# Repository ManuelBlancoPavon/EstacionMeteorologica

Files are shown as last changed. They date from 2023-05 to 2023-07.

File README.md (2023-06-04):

# Para sanarlo hay que estudiarlo (Estación meteorológica)

## Presentación

Esta estación meteorológica sirve para medir la temperatura, humedad, presión, luxes, índice UV, velocidad del viento, dirección del viento y precipitaciones.
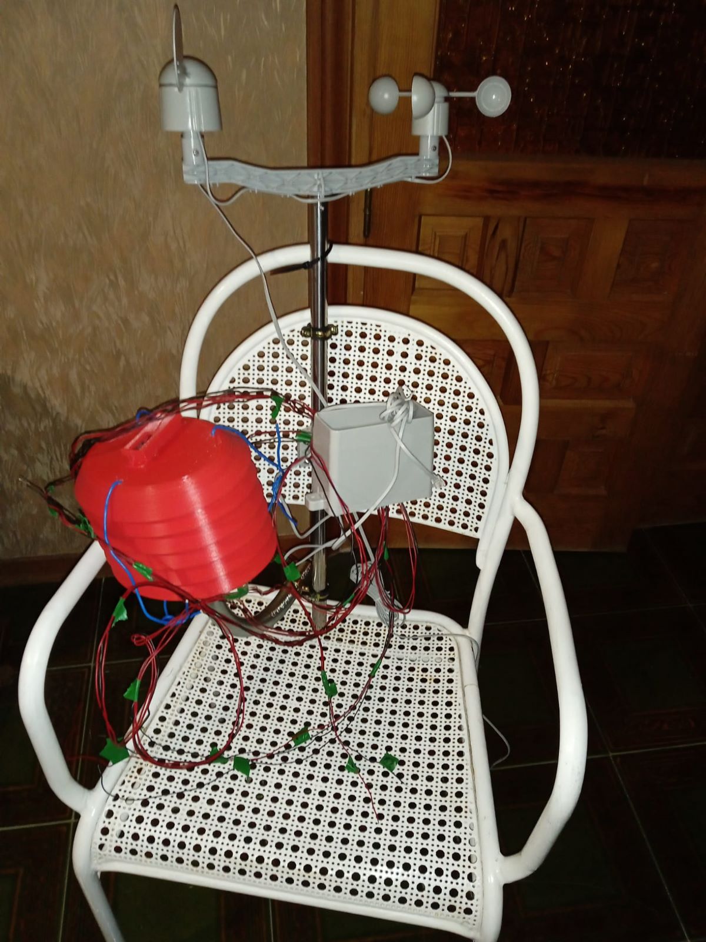
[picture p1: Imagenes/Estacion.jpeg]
Estación


## Pagina Web donde ver los datos del tiempo
>
> En construcción.
>
## Materiales

- 1x Raspberry Pi Pico W
- 1x BME280
- 1x LTR390
- 1x MQ-135
- 1x [Kit de anemómetro, veleta y pluviómetro.](https://www.argentdata.com/catalog/product_info.php?products_id=145)
- 2x Cables STEMMA QT
- 2x Conectores RJ11
- 9x Conectores de tornillo de 2 pines
- 1x Resistencias de 2k ohm
- 2x Resistencia de 4.7k ohm
- 1x Perforad

## Esquema de conexiones

- Los cables de color ocre son conexiones hechas con estaño hechas por debajo.
- Es mejor soldar a la placa unos pines hembra para poder sacar y poner la Raspberry Pi Pico W.
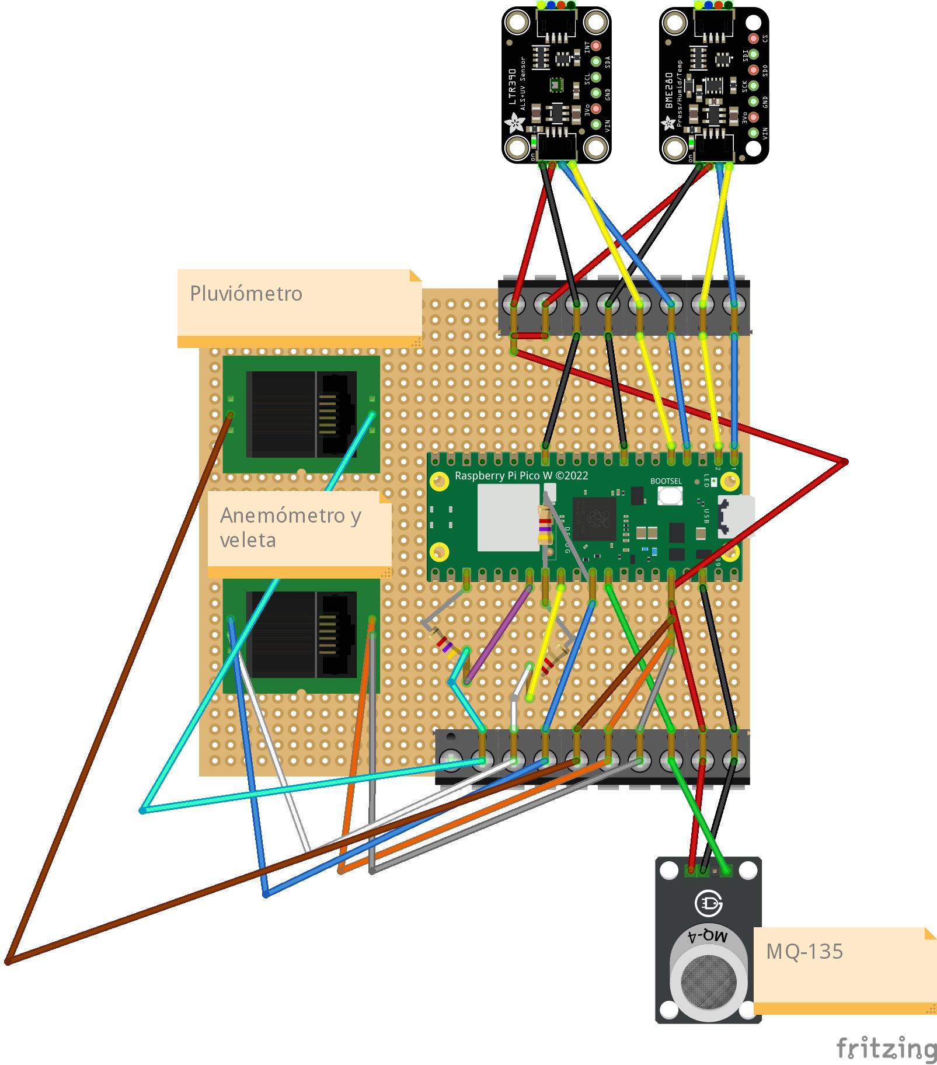
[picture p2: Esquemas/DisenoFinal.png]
Esquema

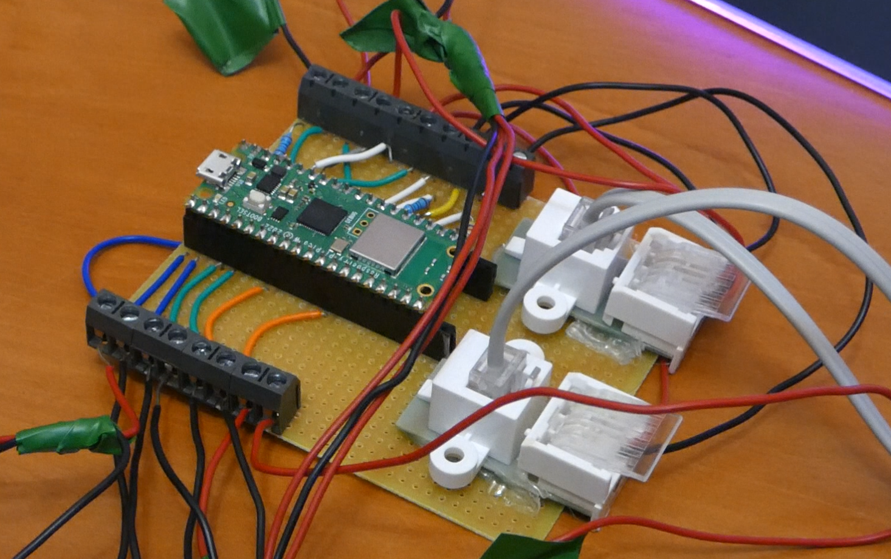
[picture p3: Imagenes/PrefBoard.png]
PrefBoard


## Programación

### Raspberry Pi Pico W

1. Mantén el botón BOOT presionado y conecta la Raspberry Pi Pico W al ordenador.
2. Descargar CircuitPython 8.x [aquí](https://circuitpython.org/board/raspberry_pi_pico_w/).
3. Arrastrar el archivo .u2f a la carpeta de la Raspberry Pi Pico W.
4. Descargar el bundle versión 8.x [aquí](https://circuitpython.org/libraries).
5. Descomprime el bundle y copia a la carpeta lib de las Raspberry Pi Pico W las siguientes librerías:

- adafruit_bme280
- adafruit_httpserver
- adafruit_register
- asyncio
- adafruit_ltr390.mpy
- adafruit_ticks.mpy
- adafruit_datetime.mpy
- adafruit_requests.mpy

6.Descargue Thonny [aquí](https://thonny.org/).
7.Abra Thonny y seleccione la Raspberry Pi Pico W como dispositivo.
8.Copie la carpeta de tests a la Raspberry Pi Pico W.
9.Compruebe que cada sensor funcione.
10.Copie el archivo main.py y settings.json a la Raspberry Pi Pico W.
11.Modifique el settings.json con los datos de su red wifi
12.Ejecute el archivo main.py
13.Y en su navegador vaya a la dirección ip 192.168.1.160/data (o la que tenga asignada) y vera como cada 15 segundos o los que quiera se actualizan los datos.
14.Cabe destacar que solo empezara a dar datos cuando los minutos acaben en 0 o 5 para que los datos cuando sean almacenados queden más bonitas las fechas.

### Servidor

#### Poniendo en marcha la base de datos

1. Descargue e instale MariaDB [aquí](https://mariadb.org/download/).
2. Ejecute script.sql en la base de datos.

#### Almacenando datos en la base de datos

1. Instale los siguientes módulos de python con pip install -r requirements.txt.
2. Descargue el archivo store.py y ejecútelo configurando cada cuánto tiempo quiere almacenar los datos.
3. Lo tendrá que hacer que se ejecute en segundo plano.
4. Ten en cuenta que este programa se adapta automáticamente a la cantidad de tiempo que hayas puesta en la configuración de la Raspberry PI Pico W.

#### Página Web

1. Descargue la carpeta app y ejecute main.py.
2. Recuerde que en host tiene que poner la ip de su ordenador.
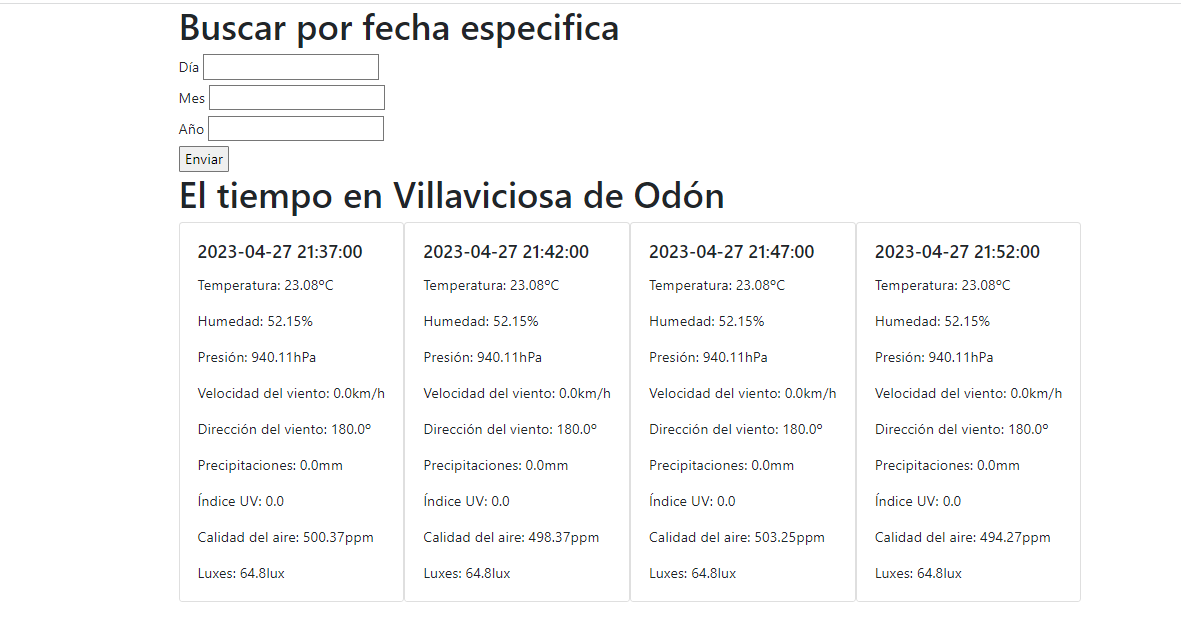
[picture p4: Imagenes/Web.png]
Web


### Creación de los procesos en segundo plano

Esto solo se aplica para Linux (yo lo he hecho en Ubuntu 22.04 aunque debería funcionar para cualquier Linux).

1. Descargue los archivos archivos tiempo_store.service y tiempo_web.service y ponga los en /etc/systemd/system.
2. Cambie en los dos archivos las rutas de donde esta la carpeta y donde esta el archivo que se tiene que ejecutar en los campos WorkingDirectory y ExecStart, no se olvide de poner su nombre de usuario en el campo User.
3. Ejecute sudo systemctl daemon-reload.
4. Ejecute sudo systemctl start tiempo_store.service y sudo systemctl start tiempo_web.service para iniciarlos.
5. Ejecute sudo systemctl enable tiempo_store.service y sudo systemctl enable tiempo_web.service para que se inicien al encender el ordenador.
6. Ejecute sudo systemctl status tiempo_store.service y sudo systemctl status tiempo_web.service para comprobar que se están ejecutando.
7. Una cosa buena de este sistema es que si uno de los procesos da error se reiniciara automáticamente.

## Montaje

1. Imprime una Stevenson screen para que los sensores no estén expuestos al sol y solo midan la temperatura del aire aunque os recomiendo que el sensor grid lo imprimáis un poco más pequeño para que quepa. Luego hacer un agujero en la parte de abajo para llevar los cables [Descargar](https://www.thingiverse.com/thing:1718334/files). Podéis poner los sensores en el sensor grid y os quedaría tal que así:
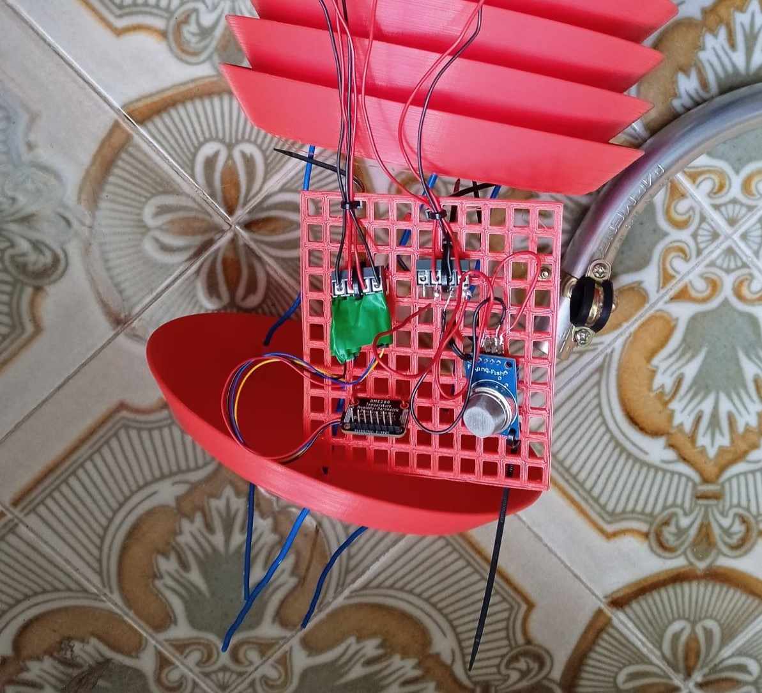
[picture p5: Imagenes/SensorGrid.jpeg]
SensorGrid

Y para el LTR390 tenéis esta carcasa [Descargar](https://www.thingiverse.com/thing:5388692). Aunque yo he hecho una modificación para que sea un poco más amplia y entre mejor lo tenéis en la carpeta impresora 3D. Y luego lo podéis poner en la parte de arriba de la Stevenson screen con silicona caliente y hacer un agujero en la parte de abajo para llevar los cables.

## Agradecimientos

Muchas gracias a mi familia, mis amigos y profesores por el apoyo que me han dado para hacer este proyecto.

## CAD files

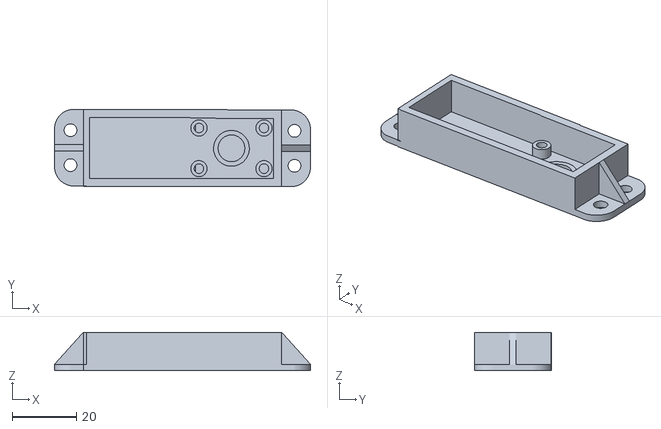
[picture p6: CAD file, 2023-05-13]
Impresora3D/LTR390_case.stl
80.0 x 24.0 x 12.0

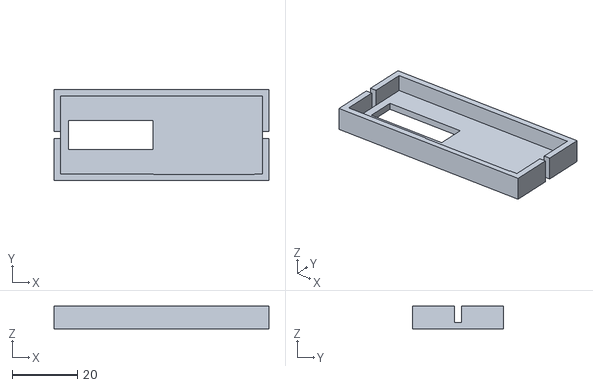
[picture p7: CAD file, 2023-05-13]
Impresora3D/LTR390_tape.stl
66.0 x 27.8 x 7.00

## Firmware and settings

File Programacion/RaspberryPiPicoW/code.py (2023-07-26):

import asyncio
import board
import keypad
import time
import math
import analogio
import busio
import os
import adafruit_ltr390
from adafruit_bme280 import basic as adafruit_bme280
from adafruit_httpserver.server import HTTPServer
from adafruit_httpserver.request import HTTPRequest
from adafruit_httpserver.response import HTTPResponse
from adafruit_httpserver.methods import HTTPMethod
from adafruit_httpserver.mime_type import MIMEType
import ipaddress
import wifi
import adafruit_datetime
import json
import socketpool
import adafruit_requests
import microcontroller

## Variables
# Wifi
ipv4 =  ipaddress.IPv4Address("192.168.1.160")
netmask =  ipaddress.IPv4Address("255.255.255.0")
gateway =  ipaddress.IPv4Address("192.168.1.1")
wifi.radio.set_ipv4_address(ipv4=ipv4,netmask=netmask,gateway=gateway)

ssid = os.getenv("WIFI_SSID")
password = os.getenv("WIFI_PASSWORD")

while True:
    try:
        print("Connecting to", ssid)
        wifi.radio.connect(ssid, password)
        print("Connected to", ssid)
        ipv4 = ipaddress.ip_address("8.8.8.8")
        print("Ping google.com: %f ms" % (wifi.radio.ping(ipv4)*1000))
        break
    except Exception as e:
        print("Error:\n", str(e))
        time.sleep(40)

pool = socketpool.SocketPool(wifi.radio)
server = HTTPServer(pool, "/static")

url = "http://worldtimeapi.org/api/timezone/Europe/Madrid"
requests = adafruit_requests.Session(pool)
# Pluviometro
agua = 0
# Anemometro
vueltas = 0
radio = 9.0
intervalo = 900
ajuste = 1.18
limite = 1000
# Veleta
volts = {0.4: 0,
         2.8: 90,
         1.8: 180,
         0.1: 270,
         1.2: 45,
         2.3: 135,
         0.8: 225,
         0.2: 315,
         1.4: 22.5,
         2.9: 112.5,
         2.6: 157.5,
         2.0: 202.5,
         0.7: 247.5,
         0.3: 292.5,
         0.6: 337.5}

## Sensores
# MQ-135
MQ135 = analogio.AnalogIn(board.GP27)
# BME280
i2c = busio.I2C(board.GP1, board.GP0)  # SCL, SDA
bme280 = adafruit_bme280.Adafruit_BME280_I2C(i2c)
# LTR390
i2c = busio.I2C(board.GP3, board.GP2)  # SCL, SDA
ltr390 = adafruit_ltr390.LTR390(i2c)
# Veleta
analog_value = analogio.AnalogIn(board.GP26)

### Codigo
## Wifi
# Conectarse a la red

print(f"Listening on http://{wifi.radio.ipv4_address}:80")
server.start(str(wifi.radio.ipv4_address))
def calcularMM():
    global agua
    mm = agua * 0.2794
    return mm

def calcularVelocidad(tiempo):
    global vueltas
    circunferencia = (2 * math.pi) * radio
    rotaciones = vueltas / 2.0
    
    distKM = (circunferencia * rotaciones) / 100000
    
    kms = distKM / tiempo
    kmh = kms * 3600
    
    return kmh * ajuste

def calcularppm():
    calibracion = 0.00322265625
    valorBruto = MQ135.value
    voltaje = valorBruto * 3.3 / 65536
    ppm = voltaje / calibracion
    return ppm

async def catch_pin_transitions2(pin):
    """Print a message when pin goes low and when it goes high."""
    with keypad.Keys((pin,), value_when_pressed=False) as keys:
        while True:
            event = keys.events.get()
            if event:
                if event.released:
                    global agua
                    agua += 1
            await asyncio.sleep(0)

async def catch_pin_transitions(pin):
    """Print a message when pin goes low and when it goes high."""
    with keypad.Keys((pin,), value_when_pressed=False) as keys:
        while True:
            event = keys.events.get()
            if event:
                if event.released:
                    global vueltas
                    vueltas += 1
            await asyncio.sleep(0)
velocidad = 0
ppm = 0
direccion = 0
temperatura = 0
humedad = 0
presion = 0
precipitaciones = 0
uvi = 0
lux = 0

async def principal():
    while True:
        try:
            global vueltas
            global agua
            global intervalo
            global velocidad
            global ppm
            global direccion
            global temperatura
            global humedad
            global presion
            global precipitaciones
            global uvi
            global lux
            agua = 0
            vueltas = 0
            await asyncio.sleep(intervalo)
            ppm = calcularppm()
            temperatura = bme280.temperature
            humedad = bme280.relative_humidity
            presion = bme280.pressure
            precipitaciones = calcularMM()
            uvi = ltr390.uvi
            lux = ltr390.lux
            velocidad = calcularVelocidad(intervalo)
            voltios = round((analog_value.value * 3.33333) / 65535, 1)
            print("Velocidad del viento", velocidad, "km/h")
            print("Temperatura: %0.1f C" % bme280.temperature)
            print("Humedad: %0.1f %%" % bme280.relative_humidity)
            print("Presion: %0.1f hPa" % bme280.pressure)
            print("Precipitaciones: ", calcularMM(), "mm")
            print("Indice de radiacion UV:", ltr390.uvi)
            print("Luxes: ", ltr390.lux, "iluminancia")
            print("Concentracion de gases: %.2f ppm" % ppm)
            if not voltios in volts:
                direccion = -1
                print("Direccion del viento desconocida")
            else:
                direccion = str(volts[voltios])
                print("Direccion del viento: " + str(volts[voltios]))
                
        except Exception as e:
            print("Error en principal")
            time.sleep(5)
            microcontroller.reset()

async def updateServer():
    timer = 0
    while True:
        try:
            print(timer)
            await asyncio.sleep(0.5)
            timer += 0.5
            server.poll()
        except Exception as e:
            print("Error en enviando los datos")
            time.sleep(5)
            microcontroller.reset()
        
@server.route("/data") 
def cpu_information_handler(request: HTTPRequest):
    try:
        global velocidad
        global ppm
        global direccion
        global temperatura
        global humedad
        global presion
        global precipitaciones
        global uvi
        global lux
        data = {
            "velocidad": round(velocidad, 2),
            "temperatura": round(temperatura, 2),
            "humedad": round(humedad, 2),
            "presion": round(presion, 2),
            "precipitaciones": round(precipitaciones, 2),
            "uvi": round(uvi, 2),
            "luxes": round(lux, 2),
            "direccion": direccion,
            "ppm": round(ppm, 2)
        }

        with HTTPResponse(request, content_type=MIMEType.TYPE_JSON) as response:
            response.send(json.dumps(data))
            
    except Exception as e:
        print("Error actualizando los datos")
        time.sleep(5)
        microcontroller.reset()

async def main():
    interrupt_task = asyncio.create_task(catch_pin_transitions(board.GP22))
    interrupt_task2 = asyncio.create_task(catch_pin_transitions2(board.GP21))
    server_task = updateServer()
    print_task = asyncio.create_task(principal())
    check_internet = asyncio.create_task(comprobarInternet())
    await asyncio.gather(interrupt_task, interrupt_task2, print_task, server_task, check_internet)

async def comprobarInternet():
    while True:
        try:
            await asyncio.sleep(300)
            ipv4 = ipaddress.ip_address("8.8.8.8")
            print("Ping google.com: %f ms" % (wifi.radio.ping(ipv4)*1000))
        except Exception as e:
            print("Se ha ido la conexion a internet")
            time.sleep(5)
            microcontroller.reset()

while True:
    response = requests.get(url)
    jsonTiempo = response.json()
    strTiempo = jsonTiempo['datetime']
    objTiempo = adafruit_datetime.datetime.fromisoformat(strTiempo)
    minutos = objTiempo.minute
    
    if minutos % 5 == 0:
        asyncio.run(main())
        break  # Salir del bucle después de llamar a asyncio.run(main())
    
    # Si minutos % 5 no es igual a 0, esperar y volver a intentarlo
    time.sleep(5)

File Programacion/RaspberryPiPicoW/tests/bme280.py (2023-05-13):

# SPDX-FileCopyrightText: 2021 ladyada for Adafruit Industries
# SPDX-License-Identifier: MIT

import time
import board
import busio
from adafruit_bme280 import basic as adafruit_bme280

# Create sensor object, using the board's default I2C bus.
i2c = busio.I2C(board.GP1, board.GP0)  # SCL, SDA
bme280 = adafruit_bme280.Adafruit_BME280_I2C(i2c)

# OR create sensor object, using the board's default SPI bus.
# spi = busio.SPI(board.GP2, MISO=board.GP0, MOSI=board.GP3)
# bme_cs = digitalio.DigitalInOut(board.GP1)
# bme280 = adafruit_bme280.Adafruit_BME280_SPI(spi, bme_cs)

while True:
    print("\nTemperature: %0.1f C" % bme280.temperature)
    print("Humidity: %0.1f %%" % bme280.relative_humidity)
    print("Pressure: %0.1f hPa" % bme280.pressure)
    time.sleep(2)

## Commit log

2023-05-13 v.1.0 Anadido la programacion y los esquematicos
    [DisenoFinal.fzz]
2023-05-13 v.2.0 Primara Release
    [DisenoFinal.fzz, LTR390_case.stl, LTR390_tape.stl]
2023-05-13 v.2.0.1 Arreglo de erratas
2023-05-13 v.2.0.2 Arreglo de erratas
2023-05-15 v.2.1 Arreglado script.sql, anadido hoja de estilos, mejorada la pagina web con optimicaciones de codigo y buscador de horas
2023-05-15 v.2.1.1 Arreglado script.sql (que se me olvido en el commit anterior)
2023-05-17 v.2.2 Anadido modo grafico a la pagina web y arreglado que no se actualizen los datos
2023-05-18 v.2.2 Anadido resumen del dia en modo cuadrado y mejorado sistema de store.py
2023-05-31 v2.3 Mejorada la programacion de la pico para que solo empize a dar los datos cuando los minutos acaben en 0 o 5 y acualizado README.md
2023-05-31 v2.3.1 Arreglado que se me olvido descomentar 2 lineas
    [code.py]
2023-06-01 v2.3.2 Arreglado error del json, cambiado el intervarlo de tiempo en code.py y en store.py no se crean entradas ducplicadas
    [code.py]
2023-06-01 v2.3.3 Modificada la pagina web para que el dia por defecto sea el dia actual
2023-06-04 v.4.1.1 Arreglado bug de que da error cuando no hay datos
2023-06-04 v.4.1.2 Arreglada sintaxis de README.md
2023-06-04 v.4.1.3 Arreglo de erraratas en README:md
2023-06-04 v.4.1.4 Arreglo de erraratas en README.md
2023-07-26 v4.2 Manejo de excepciones en code.py y rescrito store.py debido a que no funcionaba bien
